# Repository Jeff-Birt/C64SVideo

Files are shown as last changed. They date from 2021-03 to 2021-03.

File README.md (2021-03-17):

## Mk3 SVideo cable for the C64/C128

The Mk1 version was simple a low quality SVideo cable and stereo audio cable soldered to an 8-pin DIN plug. This was usable but had shortcomings, notably lack of a 330ohm resistor for the chroma signal and the whine from the SID audio input.

The Mk2 version was done in a hurray to overcome the annoying whine of the SID's audio input picking up noise. Though it was supposed to be a temporary solution it lasted a few years with a lot of patching back together.

The Mk3 cable was made with mostly things I had on hand and using the proper type of shielded cables. While a bit fiddly to build because of the tiny VGA cable wires it works very well. I milled out the PCB I used (C64_SVideo_Cable_Milled_2021-02-28.zip) but also created a version that can be professionally made by PCBWay, etc. (C64_SVideo_Cable_Pro_2021-03-17.zip). I have not had any of these PCBs made but they should be OK.  

See the Mk3_C64_SVideo_Cable_BOM.xlsx file for the BOM.

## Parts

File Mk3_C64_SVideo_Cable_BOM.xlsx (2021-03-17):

Designation | Description | Value | Link
R1 | 1/4 watt carbon resistor | 330 ohm
R2 | 1/4 watt carbon resistor | 10-100 ohm
R3 | 1/4 watt carbon resistor | 10-100 ohm
R4 | 1/4 watt carbon resistor | 10-100 ohm
JP1 | 3 position header or jumper wire
PCB1 | PCB, milled out or pro made
VGA1 | section of VGA cable
SVideo1 | Svideo cable, one end cut off | 25-235-006 | https://www.showmecables.com/premium-gold-plated-s-video-cable-6-ft
DIN 8-pin | 8-pin C64 video connector | SOI-8PINDIN-M | https://www.soigeneris.com/commodore-64-8-pin-round-din-connectors-for-video
Enc1 | Enclsoure | Bud HB-3465 | https://www.budind.com/pdf/hb3465.pdf

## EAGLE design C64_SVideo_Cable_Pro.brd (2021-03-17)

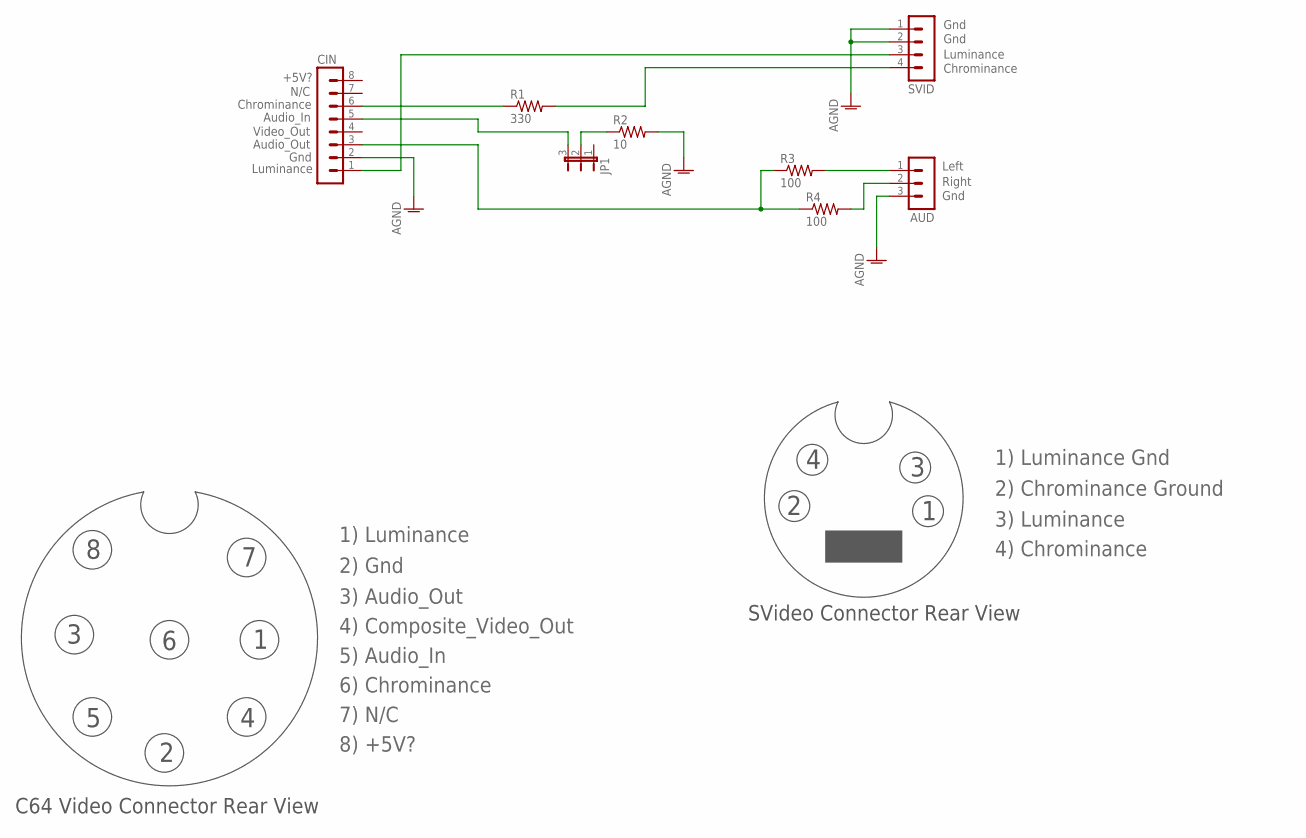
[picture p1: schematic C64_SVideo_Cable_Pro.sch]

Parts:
AUD: MA03-1
CIN: MA08-1
JP1: JP2E; JP2
R1: 330; 0309/12
R2: 10; 0309/12
R3, R4: 100; 0309/12
SVID: MA04-1

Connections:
AGND: AUD.3, CIN.2, R2.2, SVID.1, SVID.2
unnamed: CIN.6, R1.1
unnamed: R1.2, SVID.4
unnamed: AUD.1, R3.2
unnamed: AUD.2, R4.2
unnamed: CIN.5, JP1.3
unnamed: JP1.2, R2.1
unnamed: CIN.3, R3.1, R4.1
unnamed: CIN.1, SVID.3

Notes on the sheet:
Luminance
Gnd
Audio_Out
Video_Out
Audio_In
Chrominance
+5V?
N/C
Left
Right
1) Luminance
2) Gnd
3) Audio_Out
4) Composite_Video_Out
5) Audio_In
6) Chrominance
8) +5V?
7) N/C
C64 Video Connector Rear View
SVideo Connector Rear View
1) Luminance Gnd
2) Chrominance Ground
3) Luminance
4) Chrominance

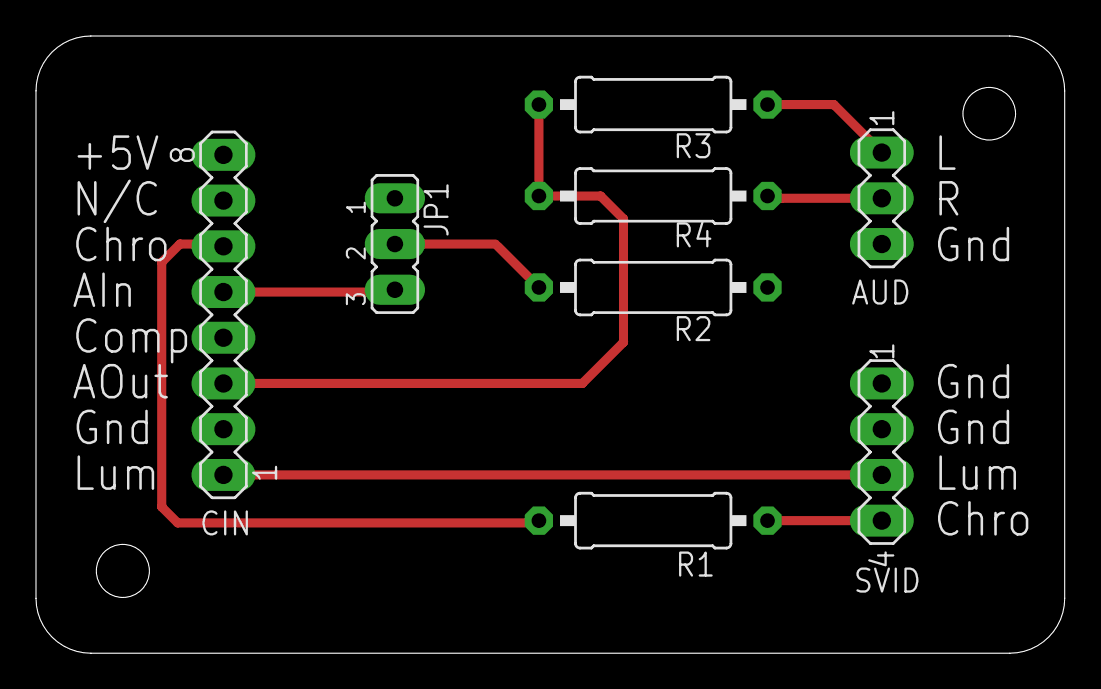
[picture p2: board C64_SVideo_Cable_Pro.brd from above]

Board: 2 copper layers, 57.1 x 34.3 mm, 8 parts (0 on the bottom side), 9 nets.
